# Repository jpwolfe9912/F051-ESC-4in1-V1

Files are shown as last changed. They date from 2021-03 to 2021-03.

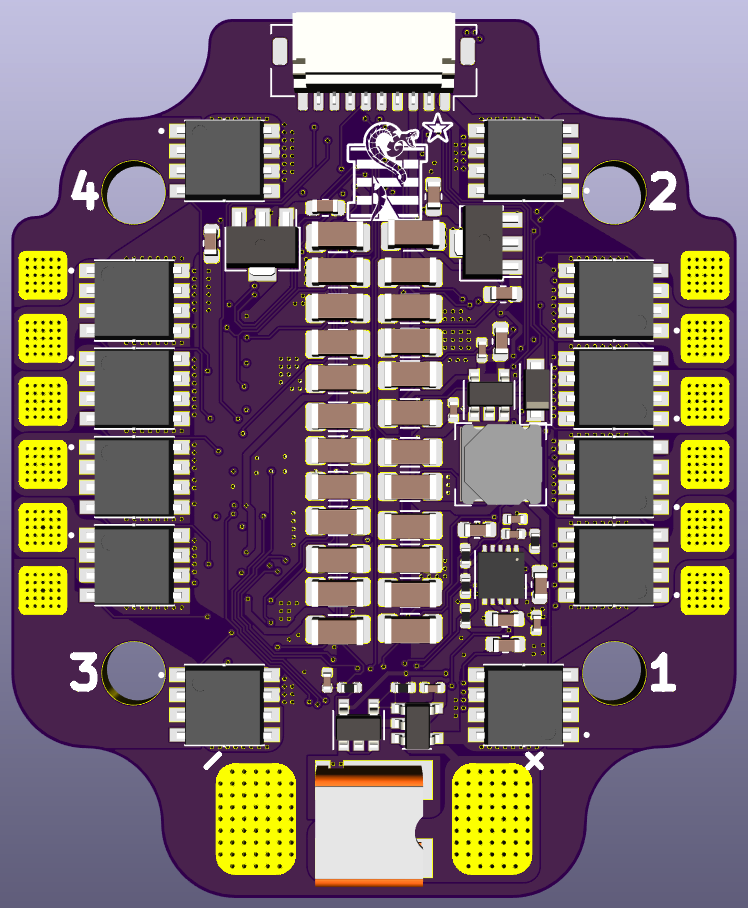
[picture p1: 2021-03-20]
PNGs/3D_Front.png

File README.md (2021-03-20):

# F051-ESC-4in1-V1

3D_Front
3D_Back
Design_Front
Design_Back
Design_FrontFill
Design_In1Fill
Design_In2Fill
Design_BackFill
Schematic_Main
Schematic_Power
Schematic_MCU
Schematic_FETDriver
Schematic_CurrSense

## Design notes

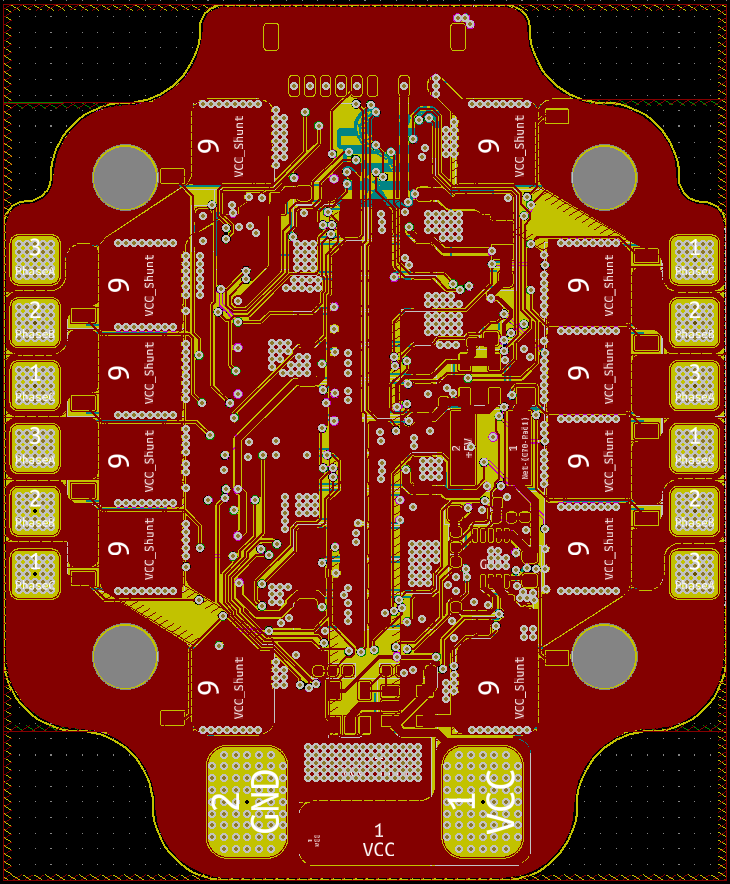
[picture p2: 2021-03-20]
PNGs/Design_FrontFill.png

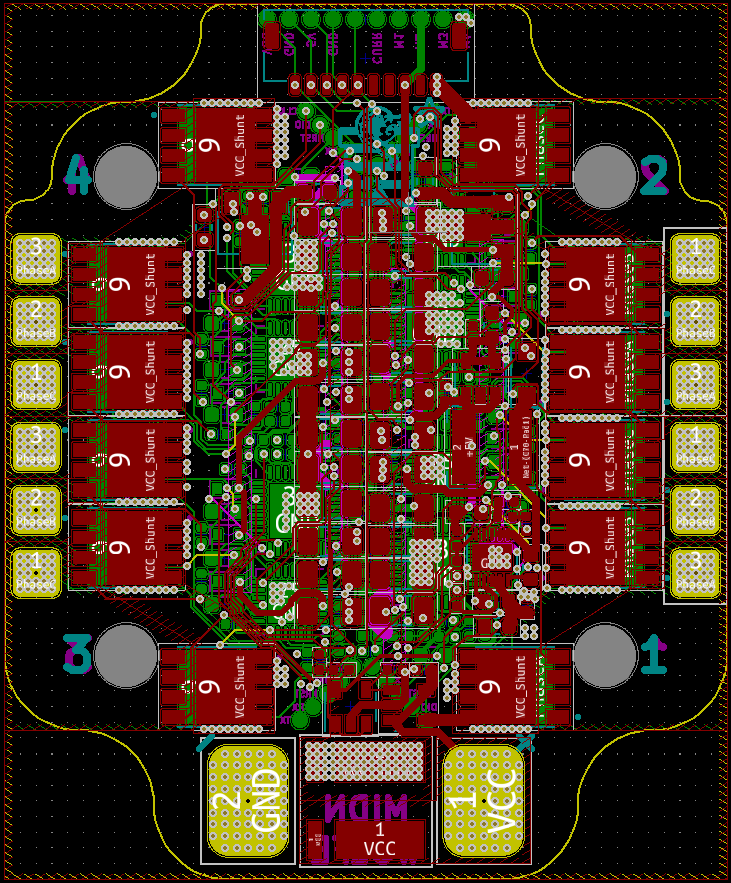
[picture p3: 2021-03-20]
PNGs/Design_Front.png

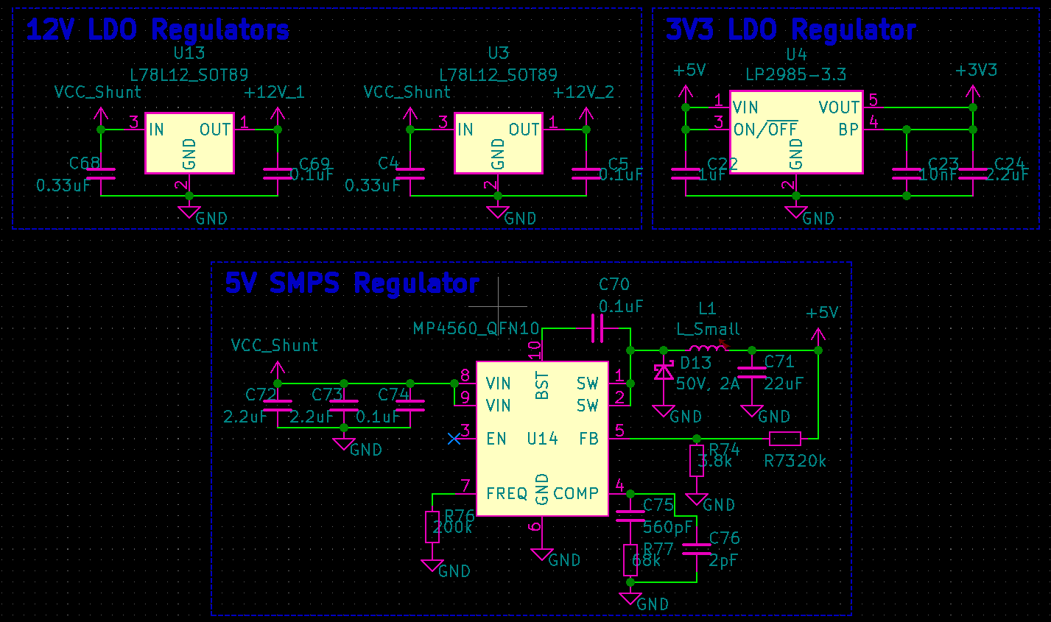
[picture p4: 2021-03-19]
PNGs/Schematic_Power.png

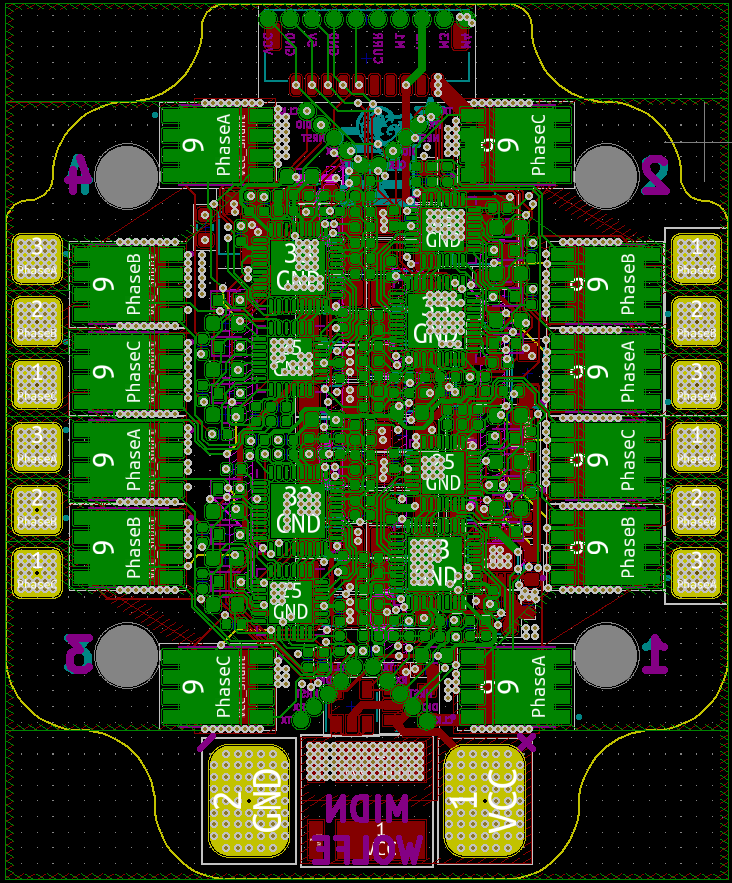
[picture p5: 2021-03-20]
PNGs/Design_Back.png

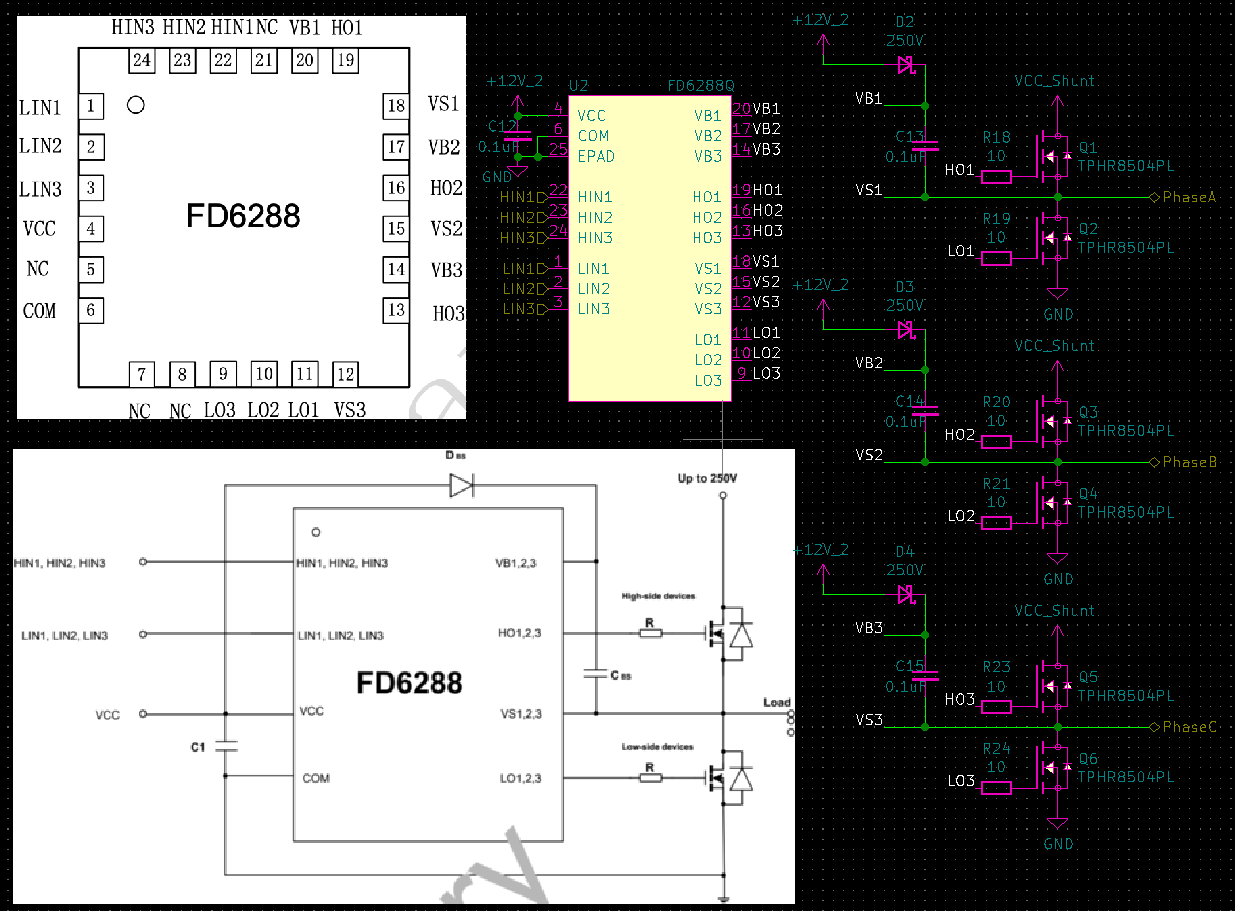
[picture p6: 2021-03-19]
PNGs/Schematic_FETDriver.png

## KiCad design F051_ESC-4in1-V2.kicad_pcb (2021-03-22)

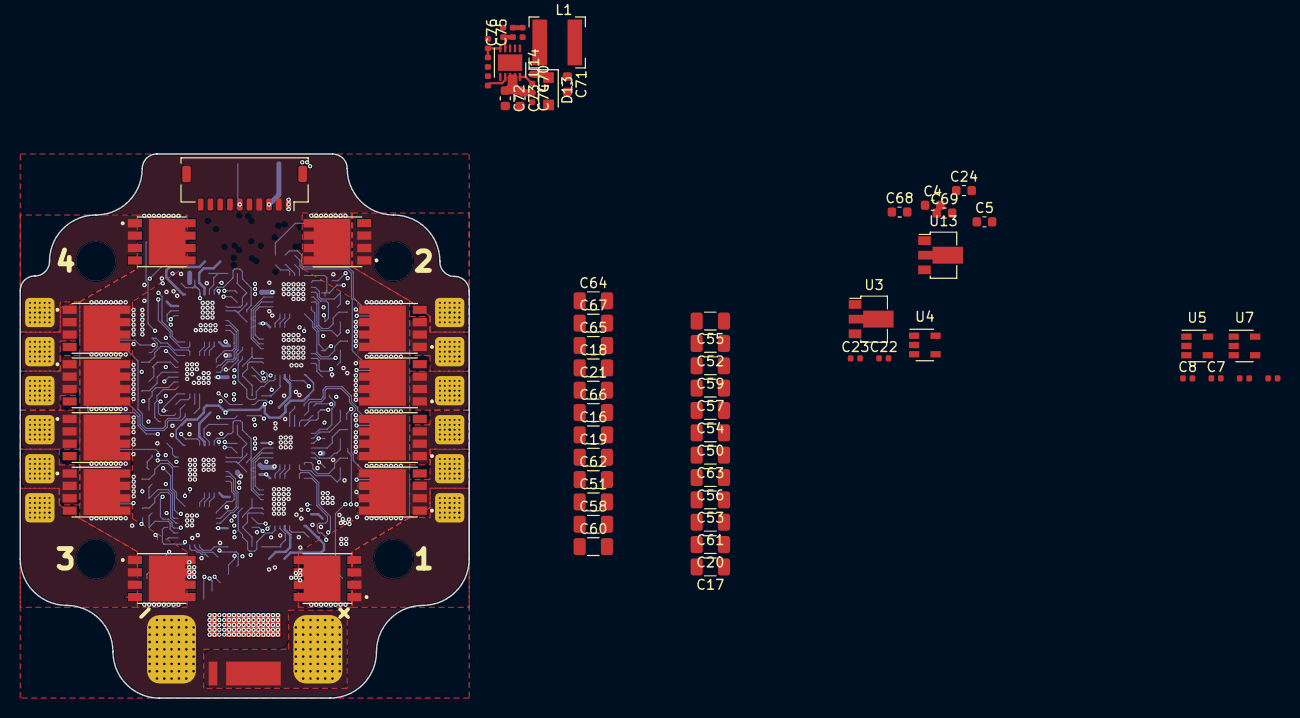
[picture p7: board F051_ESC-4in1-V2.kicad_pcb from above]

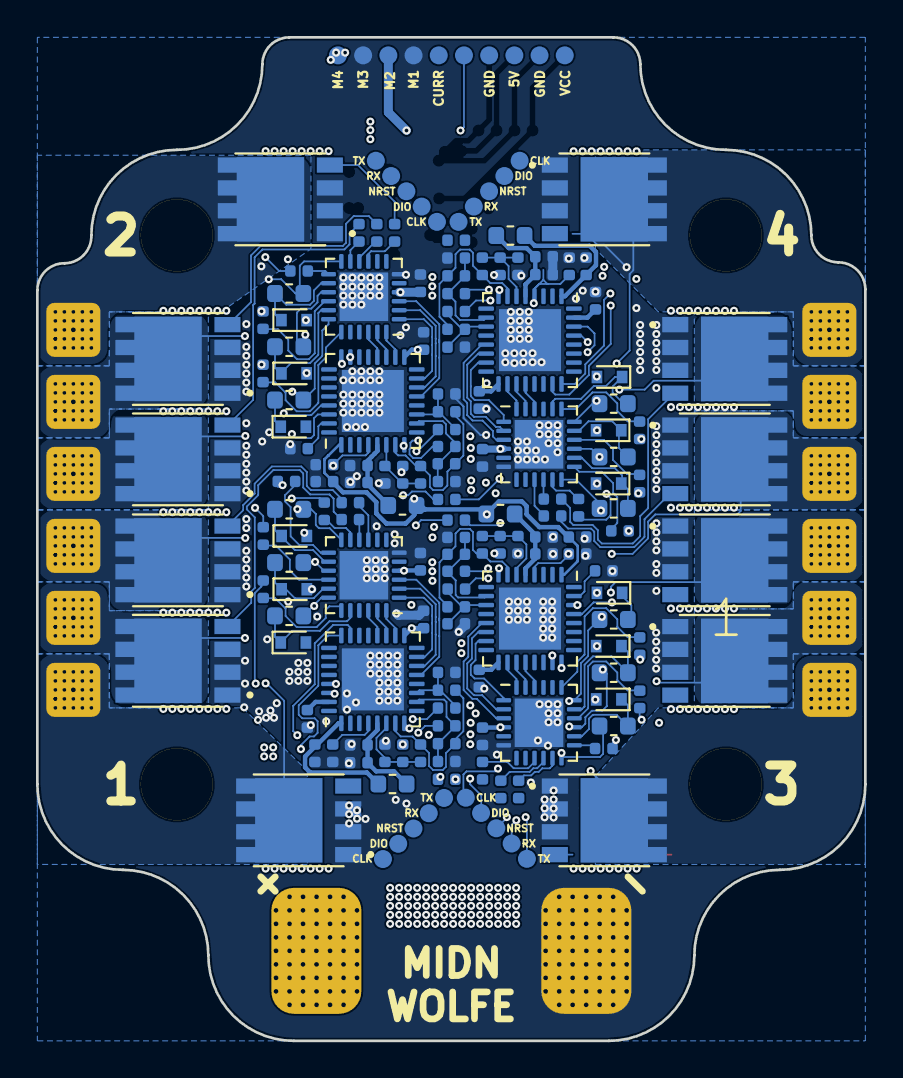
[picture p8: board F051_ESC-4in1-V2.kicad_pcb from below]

Board: 4 copper layers, 46.0 x 55.8 mm, 222 parts (147 on the bottom side), 164 nets.

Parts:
C1, C23, C27, C32, C41: 10nF; C_0402_1005Metric
C2, C22, C28, C33, C42: 1uF; C_0402_1005Metric
C3, C6, C7, C9, C11, C12, C29, C30, C31, C34, C35, C36, C37, C43, C44, C45, C46, C70, C74: 0.1uF; C_0402_1005Metric
C4, C68: 0.33uF; C_0603_1608Metric
C5, C10, C13, C14, C15, C25, C26, C38, C39, C40, C47, C48, C49, C69: 0.1uF; C_0603_1608Metric
C8: 3.3nF; C_0402_1005Metric
C16, C17, C18, C19, C20, C21, C50, C51, C52, C53, C54, C55, C56, C57, C58, C59, C60, C61, C62, C63, C64, C65, C66, C67: 47uF; C_1206_3216Metric
C24, C72, C73: 2.2uF; C_0603_1608Metric
C71: 22uF; C_0603_1608Metric
C75: 560pF; C_0402_1005Metric
C76: 2pF; C_0402_1005Metric
D1, D2, D3, D4, D5, D6, D7, D8, D9, D10, D11, D12: 250V; D_SOD-523
D13: 50V, 2A; D_SOD-123F
FB1, FB2, FB3, FB4: 100@100MHz; L_0603_1608Metric
H1, H2, H3, H4: MountingHole_Pad; MountingHole_4in1ESC
J1: Conn_01x02; Conn_PowerPad_4in1
J2: Conn_01x10; JST_SHL_SM10B-SHLS-TF_1x10-1MP_P1.00mm_Horizontal
J3, J4, J5, J7: Conn_01x05; Conn_Debug
J6, J8, J11, J14: Conn_01x03; Conn_MotorPhase
J9: Conn_01x10; Conn_FC_Solder_10
L1: L_Small; L_Bourns-SRN5020
Q1, Q2, Q3, Q4, Q5, Q6, Q7, Q8, Q9, Q10, Q11, Q12, Q13, Q14, Q15, Q16, Q17, Q18, Q19, Q20, Q21, Q22, Q23, Q24: TPHR8504PL
R1: 0m30; R_Shunt_Vishay_WSLP2726
R2: 60k; R_0402_1005Metric
R3: 500; R_0402_1005Metric
R4, R5, R6, R18, R19, R20, R21, R22, R23, R24, R25, R26, R49, R50, R51, R52, R53, R54, R66, R67, R68, R69, R70, R71: 10; R_0402_1005Metric
R7, R8, R9, R10, R12, R13, R27, R28, R29, R30, R32, R33, R38, R39, R40, R41, R43, R44, R55, R56, R57, R58, R60, R61: 10k; R_0402_1005Metric
R11, R14, R15, R16, R17, R31, R34, R35, R36, R37, R42, R45, R46, R47, R48, R59, R62, R63, R64, R65: 1k; R_0402_1005Metric
R73: 20k; R_0402_1005Metric
R74: 3.8k; R_0402_1005Metric
R76: 200k; R_0402_1005Metric
R77: 68k; R_0402_1005Metric
U1, U8, U9, U11: STM32F051K6Ux; QFN-32-1EP_5x5mm_P0.5mm_EP3.45x3.45mm
U2, U6, U10, U12: FD6288Q; QFN-24-1EP_4x4mm_P0.5mm_EP2.7x2.7mm
U3, U13: L78L12_SOT89; SOT-89-3
U4: LP2985-3.3; SOT-23-5
U5: INA139; SOT-23-5
U7: OPA340NA; SOT-23-5
U14: MP4560_QFN10; DFN-10-1EP_3x3mm_P0.5mm_EP1.7x2.5mm

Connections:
+3.3VA_1: C1.1, C2.1, FB1.1, U1.5
+3.3VA_2: C27.1, C28.1, FB2.1, U8.5
+3.3VA_3: C32.1, C33.1, FB3.1, U9.5
+3.3VA_4: C41.1, C42.1, FB4.1, U11.5
+3V3: C3.1, C6.1, C23.1, C24.1, C29.1, C30.1, C34.1, C35.1, C43.1, C44.1, FB1.2, FB2.2, FB3.2, FB4.2, U1.1, U1.17, U4.4, U4.5, U7.5, U8.1, U8.17, U9.1, U9.17, U11.1, U11.17
+5V: C22.1, C71.1, J2.3, J9.3, L1.2, R73.1, U4.1, U4.3
+12V_1: C37.1, C46.1, C69.1, D7.2, D8.2, D9.2, D10.2, D11.2, D12.2, U10.4, U12.4, U13.1
+12V_2: C5.1, C9.1, C12.1, D1.2, D2.2, D3.2, D4.2, D5.2, D6.2, U2.4, U3.1, U6.4
/Curent Sense/CURR: C8.2, J2.6, J9.6, R3.1
/MCU 1/BOOT0: R17.1, U1.31
/MCU 1/HIN1: U1.18, U2.24
/MCU 1/HIN2: U1.19, U2.23
/MCU 1/LIN1: U1.15, U2.1
/MCU 1/LIN2: U1.14, U2.2
/MCU 1/LIN3: U1.13, U2.3
/MCU 1/NRST: C11.1, J3.3, U1.4
/MCU 1/PhaseA: C13.2, J6.3, Q1.1, Q1.2, Q1.3, Q2.5, Q2.6, Q2.7, Q2.8, Q2.9, R7.2, U2.18
/MCU 1/PhaseB: C14.2, J6.2, Q3.1, Q3.2, Q3.3, Q4.5, Q4.6, Q4.7, Q4.8, Q4.9, R9.2, U2.15
/MCU 1/PhaseC: C15.2, J6.1, Q5.1, Q5.2, Q5.3, Q6.5, Q6.6, Q6.7, Q6.8, Q6.9, R12.2, U2.12
/MCU 1/SWCLK: J3.1, U1.24
/MCU 1/SWDIO: J3.2, U1.23
/MCU 1/SenseA: R7.1, R8.1, R14.2, U1.11
/MCU 1/SenseB: R9.1, R10.1, R15.2, U1.10
/MCU 1/SenseC: R12.1, R13.1, R16.2, U1.6
/MCU 1/SenseCOM: R8.2, R10.2, R13.2, U1.7
/MCU 1/USART1_RX: J3.4, U1.30
/MCU 1/USART1_TX: J3.5, U1.29
/MCU 2/BOOT0: R37.1, U8.31
/MCU 2/HIN1: U6.24, U8.18
/MCU 2/HIN2: U6.23, U8.19
/MCU 2/LIN1: U6.1, U8.15
/MCU 2/LIN2: U6.2, U8.14
/MCU 2/LIN3: U6.3, U8.13
/MCU 2/NRST: C31.1, J5.3, U8.4
/MCU 2/PhaseA: C10.2, J8.3, Q7.1, Q7.2, Q7.3, Q8.5, Q8.6, Q8.7, Q8.8, Q8.9, R27.2, U6.18
/MCU 2/PhaseB: C25.2, J8.2, Q9.1, Q9.2, Q9.3, Q10.5, Q10.6, Q10.7, Q10.8, Q10.9, R29.2, U6.15
/MCU 2/PhaseC: C26.2, J8.1, Q11.1, Q11.2, Q11.3, Q12.5, Q12.6, Q12.7, Q12.8, Q12.9, R32.2, U6.12
/MCU 2/SWCLK: J5.1, U8.24
/MCU 2/SWDIO: J5.2, U8.23
/MCU 2/SenseA: R27.1, R28.1, R34.2, U8.11
/MCU 2/SenseB: R29.1, R30.1, R35.2, U8.10
/MCU 2/SenseC: R32.1, R33.1, R36.2, U8.6
/MCU 2/SenseCOM: R28.2, R30.2, R33.2, U8.7
/MCU 2/USART1_RX: J5.4, U8.30
/MCU 2/USART1_TX: J5.5, U8.29
/MCU 3/BOOT0: R48.1, U9.31
/MCU 3/HIN1: U9.18, U10.24
/MCU 3/HIN2: U9.19, U10.23
/MCU 3/LIN1: U9.15, U10.1
/MCU 3/LIN2: U9.14, U10.2
/MCU 3/LIN3: U9.13, U10.3
/MCU 3/NRST: C36.1, J4.3, U9.4
/MCU 3/PhaseA: C38.2, J11.3, Q13.1, Q13.2, Q13.3, Q14.5, Q14.6, Q14.7, Q14.8, Q14.9, R38.2, U10.18
/MCU 3/PhaseB: C39.2, J11.2, Q15.1, Q15.2, Q15.3, Q16.5, Q16.6, Q16.7, Q16.8, Q16.9, R40.2, U10.15
/MCU 3/PhaseC: C40.2, J11.1, Q17.1, Q17.2, Q17.3, Q18.5, Q18.6, Q18.7, Q18.8, Q18.9, R43.2, U10.12
/MCU 3/SWCLK: J4.1, U9.24
/MCU 3/SWDIO: J4.2, U9.23
/MCU 3/SenseA: R38.1, R39.1, R45.2, U9.11
/MCU 3/SenseB: R40.1, R41.1, R46.2, U9.10
/MCU 3/SenseC: R43.1, R44.1, R47.2, U9.6
/MCU 3/SenseCOM: R39.2, R41.2, R44.2, U9.7
/MCU 3/USART1_RX: J4.4, U9.30
/MCU 3/USART1_TX: J4.5, U9.29
/MCU 4/BOOT0: R65.1, U11.31
/MCU 4/HIN1: U11.18, U12.24
/MCU 4/HIN2: U11.19, U12.23
/MCU 4/LIN1: U11.15, U12.1
/MCU 4/LIN2: U11.14, U12.2
/MCU 4/LIN3: U11.13, U12.3
/MCU 4/NRST: C45.1, J7.3, U11.4
/MCU 4/PhaseA: C47.2, J14.3, Q19.1, Q19.2, Q19.3, Q20.5, Q20.6, Q20.7, Q20.8, Q20.9, R55.2, U12.18
/MCU 4/PhaseB: C48.2, J14.2, Q21.1, Q21.2, Q21.3, Q22.5, Q22.6, Q22.7, Q22.8, Q22.9, R57.2, U12.15
/MCU 4/PhaseC: C49.2, J14.1, Q23.1, Q23.2, Q23.3, Q24.5, Q24.6, Q24.7, Q24.8, Q24.9, R60.2, U12.12
/MCU 4/SWCLK: J7.1, U11.24
/MCU 4/SWDIO: J7.2, U11.23
/MCU 4/SenseA: R55.1, R56.1, R62.2, U11.11
/MCU 4/SenseB: R57.1, R58.1, R63.2, U11.10
/MCU 4/SenseC: R60.1, R61.1, R64.2, U11.6
/MCU 4/SenseCOM: R56.2, R58.2, R61.2, U11.7
/MCU 4/USART1_RX: J7.4, U11.30
/MCU 4/USART1_TX: J7.5, U11.29
/MOSFET Driver 1/HIN1: U1.20, U2.22
/MOSFET Driver 1/HO1: R18.2, U2.19
/MOSFET Driver 1/HO2: R20.2, U2.16
/MOSFET Driver 1/HO3: R23.2, U2.13
/MOSFET Driver 1/LO1: R19.2, U2.11
/MOSFET Driver 1/LO2: R21.2, U2.10
/MOSFET Driver 1/LO3: R24.2, U2.9
/MOSFET Driver 1/VB1: C13.1, D2.1, U2.20
/MOSFET Driver 1/VB2: C14.1, D3.1, U2.17
/MOSFET Driver 1/VB3: C15.1, D4.1, U2.14
/MOSFET Driver 2/HIN1: U6.22, U8.20
/MOSFET Driver 2/HO1: R4.2, U6.19
/MOSFET Driver 2/HO2: R6.2, U6.16
/MOSFET Driver 2/HO3: R25.2, U6.13
/MOSFET Driver 2/LO1: R5.2, U6.11
/MOSFET Driver 2/LO2: R22.2, U6.10
/MOSFET Driver 2/LO3: R26.2, U6.9
/MOSFET Driver 2/VB1: C10.1, D1.1, U6.20
/MOSFET Driver 2/VB2: C25.1, D5.1, U6.17
/MOSFET Driver 2/VB3: C26.1, D6.1, U6.14
/MOSFET Driver 3/HIN1: U9.20, U10.22
/MOSFET Driver 3/HO1: R49.2, U10.19
/MOSFET Driver 3/HO2: R51.2, U10.16
/MOSFET Driver 3/HO3: R53.2, U10.13
/MOSFET Driver 3/LO1: R50.2, U10.11
/MOSFET Driver 3/LO2: R52.2, U10.10
/MOSFET Driver 3/LO3: R54.2, U10.9
/MOSFET Driver 3/VB1: C38.1, D7.1, U10.20
/MOSFET Driver 3/VB2: C39.1, D8.1, U10.17
/MOSFET Driver 3/VB3: C40.1, D9.1, U10.14
/MOSFET Driver 4/HIN1: U11.20, U12.22
/MOSFET Driver 4/HO1: R66.2, U12.19
/MOSFET Driver 4/HO2: R68.2, U12.16
/MOSFET Driver 4/HO3: R70.2, U12.13
/MOSFET Driver 4/LO1: R67.2, U12.11
/MOSFET Driver 4/LO2: R69.2, U12.10
/MOSFET Driver 4/LO3: R71.2, U12.9
/MOSFET Driver 4/VB1: C47.1, D10.1, U12.20
/MOSFET Driver 4/VB2: C48.1, D11.1, U12.17
/MOSFET Driver 4/VB3: C49.1, D12.1, U12.14
/PWM_1: J2.7, J9.7, R11.2
/PWM_2: J2.8, J9.8, R31.2
/PWM_3: J2.9, J9.9, R42.2
/PWM_4: J2.10, J9.10, R59.2
GND: C1.2, C2.2, C3.2, C4.2, C5.2, C6.2, C7.1, C8.1, C9.2, C11.2, C12.2, C16.1, C17.1, C18.1, C19.1, C20.1, C21.1, C22.2, C23.2, C24.2, C27.2, C28.2, C29.2, C30.2, C31.2, C32.2, C33.2, C34.2, C35.2, C36.2, C37.2, C41.2, C42.2, C43.2, C44.2, C45.2, C46.2, C50.1, C51.1, C52.1, C53.1, C54.1, C55.1, C56.1, C57.1, C58.1, C59.1, C60.1, C61.1, C62.1, C63.1, C64.1, C65.1, C66.1, C67.1, C68.2, C69.2, C71.2, C72.2, C73.2, C74.2, C76.2, D13.2, H1.1, H2.1, H3.1, H4.1, J1.2, J2.2, J2.4, J9.2, J9.4, Q2.1, Q2.2, Q2.3, Q4.1, Q4.2, Q4.3, Q6.1, Q6.2, Q6.3, Q8.1, Q8.2, Q8.3, Q10.1, Q10.2, Q10.3, Q12.1, Q12.2, Q12.3, Q14.1, Q14.2, Q14.3, Q16.1, Q16.2, Q16.3, Q18.1, Q18.2, Q18.3, Q20.1, Q20.2, Q20.3, Q22.1, Q22.2, Q22.3, Q24.1, Q24.2, Q24.3, R2.2, R14.1, R15.1, R16.1, R17.2, R34.1, R35.1, R36.1, R37.2, R45.1, R46.1, R47.1, R48.2, R62.1, R63.1, R64.1, R65.2, R74.2, R76.2, R77.2, U1.33, U2.6, U2.25, U3.2, U4.2, U5.2, U6.6, U6.25, U7.2, U8.33, U9.33, U10.6, U10.25, U11.33, U12.6, U12.25, U13.2, U14.6
unnamed: C70.1, D13.1, L1.1, U14.1, U14.2
unnamed: C70.2, U14.10
unnamed: C75.1, C76.1, U14.4
unnamed: C75.2, R77.1
unnamed: Q1.4, R18.1
unnamed: Q2.4, R19.1
unnamed: Q3.4, R20.1
unnamed: Q4.4, R21.1
unnamed: Q5.4, R23.1
unnamed: Q6.4, R24.1
unnamed: Q7.4, R4.1
unnamed: Q8.4, R5.1
unnamed: Q9.4, R6.1
unnamed: Q10.4, R22.1
unnamed: Q11.4, R25.1
unnamed: Q12.4, R26.1
unnamed: Q13.4, R49.1
unnamed: Q14.4, R50.1
unnamed: Q15.4, R51.1
unnamed: Q16.4, R52.1
unnamed: Q17.4, R53.1
unnamed: Q18.4, R54.1
unnamed: Q19.4, R66.1
unnamed: Q20.4, R67.1
unnamed: Q21.4, R68.1
unnamed: Q22.4, R69.1
unnamed: Q23.4, R70.1
unnamed: Q24.4, R71.1
unnamed: R2.1, U5.1, U7.4
unnamed: R3.2, U7.1, U7.3
unnamed: R11.1, U1.8
unnamed: R31.1, U8.8
unnamed: R42.1, U9.8
unnamed: R59.1, U11.8
unnamed: R73.2, R74.1, U14.5
unnamed: R76.1, U14.7
VCC: C7.2, J1.1, R1.1, U5.3, U5.5
VCC_Shunt: C4.1, C16.2, C17.2, C18.2, C19.2, C20.2, C21.2, C50.2, C51.2, C52.2, C53.2, C54.2, C55.2, C56.2, C57.2, C58.2, C59.2, C60.2, C61.2, C62.2, C63.2, C64.2, C65.2, C66.2, C67.2, C68.1, C72.1, C73.1, C74.1, J2.1, J9.1, Q1.5, Q1.6, Q1.7, Q1.8, Q1.9, Q3.5, Q3.6, Q3.7, Q3.8, Q3.9, Q5.5, Q5.6, Q5.7, Q5.8, Q5.9, Q7.5, Q7.6, Q7.7, Q7.8, Q7.9, Q9.5, Q9.6, Q9.7, Q9.8, Q9.9, Q11.5, Q11.6, Q11.7, Q11.8, Q11.9, Q13.5, Q13.6, Q13.7, Q13.8, Q13.9, Q15.5, Q15.6, Q15.7, Q15.8, Q15.9, Q17.5, Q17.6, Q17.7, Q17.8, Q17.9, Q19.5, Q19.6, Q19.7, Q19.8, Q19.9, Q21.5, Q21.6, Q21.7, Q21.8, Q21.9, Q23.5, Q23.6, Q23.7, Q23.8, Q23.9, R1.2, U3.3, U5.4, U13.3, U14.8, U14.9

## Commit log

2021-03-16 Adding new files
    [CurrentSense.sch, F051_ESC-4in1-V1.kicad_pcb, F051_ESC-4in1-V1.sch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]
2021-03-16 Added the rest of the phases and their associated components
    [CurrentSense.sch, F051_ESC-4in1-V1.kicad_pcb, F051_ESC-4in1-V1.sch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]
2021-03-16 Updated Design
    [F051_ESC-4in1-V1.kicad_pcb]
2021-03-16 Added a test circuit to figure out best configuration
    [CurrentSense.sch, F051_ESC-4in1-V1.kicad_pcb, F051_ESC-4in1-V1.sch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]
2021-03-17 More design changes
    [CurrentSense.sch, F051_ESC-4in1-V1.kicad_pcb, F051_ESC-4in1-V1.sch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]
2021-03-17 Circuit added to board
    [F051_ESC-4in1-V1.kicad_pcb]
2021-03-17 Finalized back layer and added FETs to front layer
    [F051_ESC-4in1-V1.kicad_pcb, MCU_3.sch, MCU_4.sch]
2021-03-17 Added pads for battery and debugging
    [F051_ESC-4in1-V1.kicad_pcb, F051_ESC-4in1-V1.sch, MCU_1.sch]
2021-03-17 Addition of 5V Regulator
    [CurrentSense.sch, F051_ESC-4in1-V1.kicad_pcb, F051_ESC-4in1-V1.sch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]
2021-03-17 Added more planes, rearranged 5V circuit
    [F051_ESC-4in1-V1.kicad_pcb]
2021-03-17 Added 3V3 regulator and connected it to rest of board
    [F051_ESC-4in1-V1.kicad_pcb, MCU_2.sch, MCU_3.sch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]
2021-03-18 Connected a lot of stuff
    [F051_ESC-4in1-V1.kicad_pcb]
2021-03-18 A few more traces laid out
    [F051_ESC-4in1-V1.kicad_pcb]
2021-03-18 Rerouted a bunch of the phase traces so they are shorter
    [F051_ESC-4in1-V1.kicad_pcb, MCU_1.sch]
2021-03-18 More routing of phase traces
    [F051_ESC-4in1-V1.kicad_pcb]
2021-03-18 A lot more traces added
    [F051_ESC-4in1-V1.kicad_pcb]
2021-03-19 Routed a lot more stuff. Just some more GND and VCC vias to add
    [F051_ESC-4in1-V1.kicad_pcb]
2021-03-19 More GND and VCC vias and planes added. Moved around some sense resistors to expose GND
    [F051_ESC-4in1-V1.kicad_pcb]
2021-03-19 Finished all traces and vias
    [F051_ESC-4in1-V1.kicad_pcb, F051_ESC-4in1-V1.sch, MCU_1.sch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]
2021-03-19 Added more PNGs
    [CurrentSense.sch, F051_ESC-4in1-V1.sch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]
2021-03-19 Deleted some extra files
    [FET_Driver.sch, FET_Driver_1.sch, FET_Driver_2.sch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]
2021-03-19 Moved around some traces to create bigger fills
    [F051_ESC-4in1-V1.kicad_pcb]
2021-03-19 Changed shunt resistor footprint and changed edge cuts to accomodate larger size
    [F051_ESC-4in1-V1.kicad_pcb, MCU_1.sch]
2021-03-20 Some graphical additions
    [CurrentSense.sch, F051_ESC-4in1-V1.kicad_pcb]
2021-03-20 Changed input filtering caps to 47uF from 0.1uF
    [F051_ESC-4in1-V1.sch]
2021-03-20 Updated PNGS
    [CurrentSense.sch]
2021-03-20 Adjusted some of the fills to match the grid
    [F051_ESC-4in1-V1.kicad_pcb]
2021-03-22 Cleared front layer and rearranging
    [F051_ESC-4in1-V1.kicad_pcb, F051_ESC-4in1-V2.kicad_pcb, F051_ESC-4in1-V2.sch]
